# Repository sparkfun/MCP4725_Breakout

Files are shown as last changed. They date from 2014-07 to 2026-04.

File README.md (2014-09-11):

MCP4725_Breakout
================
[MCP4725_Breakout  
*Breakout Board for MCP4725 I2C DAC (BOB-12918)*](https://www.sparkfun.com/products/12918)

The MCP4725 is an I<sup>2</sup>C controlled Digital-to-Analog converter (DAC). It allows you to send an analog signal from a digital source.

Repository Contents
-------------------
* **/Hardware** - Eagle PCB layout files
* **/Production** - Test bed files and production panel files

Version History
---------------
* [BOB-08736](https://www.sparkfun.com/products/8736) -Version 1.3. Now retired. 

License Information
-------------------
The hardware is released under [Creative Commons ShareAlike 4.0 International](https://creativecommons.org/licenses/by-sa/4.0/).
The code is beerware; if you see me (or any other SparkFun employee) at the local, and you've found our code helpful, please buy us a round!

Distributed as-is; no warranty is given.

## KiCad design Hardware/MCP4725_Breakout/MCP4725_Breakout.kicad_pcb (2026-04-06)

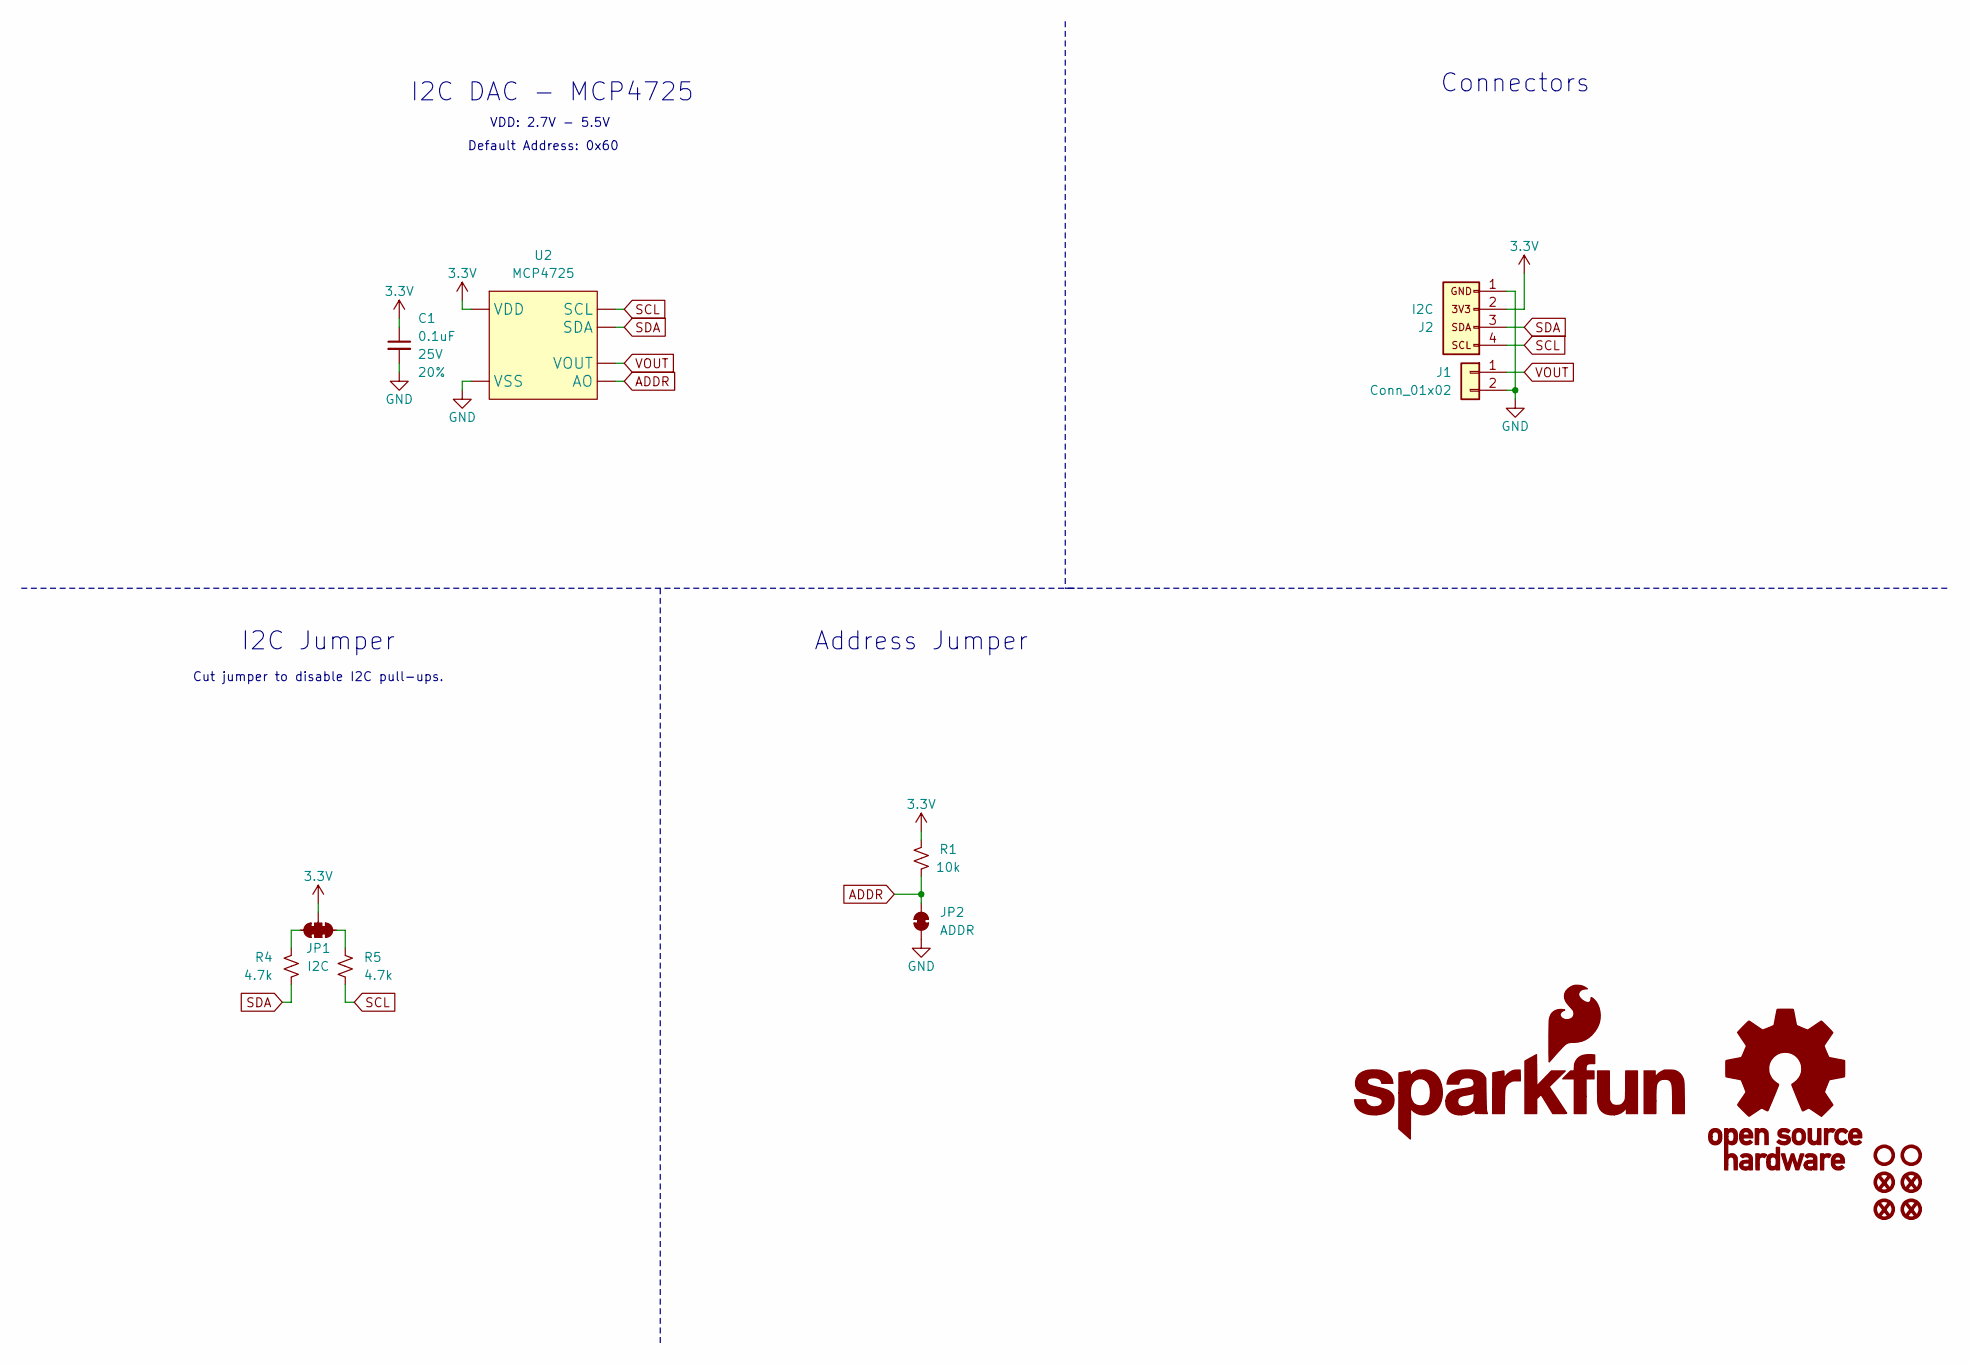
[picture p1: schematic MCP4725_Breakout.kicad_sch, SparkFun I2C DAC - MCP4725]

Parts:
C1: 0.1uF; C_0603_1608Metric; Voltage 25V; Tolerance 20%
FID1, FID2, FID3, FID4: Fiducial_0.5mm; Fiducial_0.5mm_Mask1mm
G1: OSHW_Logo; Creative_Commons_License
G2: SparkFun_Logo
J1: Conn_01x02; 1x02_P2.54mm
J2: I2C; 1x04_P2.54mm
JP1: I2C; Jumper_3_NC-2_Trace
JP2: ADDR; Jumper_2_NC_Trace
R1: 10k; R_0603_1608Metric
R4, R5: 4.7k; R_0603_1608Metric
ST1, ST2: Standoff
U2: MCP4725; SOT23-6

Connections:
3.3V: C1.1, J2.2, JP1.2 (B), R1.2, U2.3 (VDD)
ADDR: JP2.2 (B), R1.1, U2.6 (AO)
GND: C1.2, J1.2, J2.1, JP2.1 (A), U2.2 (VSS)
unnamed: JP1.1 (A), R5.2
unnamed: JP1.3 (C), R4.2
SCL: J2.4, R5.1, U2.5 (SCL)
SDA: J2.3, R4.1, U2.4 (SDA)
VOUT: J1.1, U2.1 (VOUT)

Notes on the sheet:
Default Address: 0x60
VDD: 2.7V - 5.5V
I2C DAC - MCP4725
Cut jumper to disable I2C pull-ups.
Address Jumper
I2C Jumper
Connectors

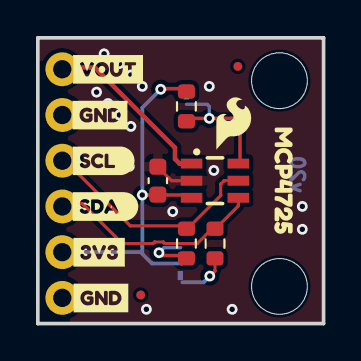
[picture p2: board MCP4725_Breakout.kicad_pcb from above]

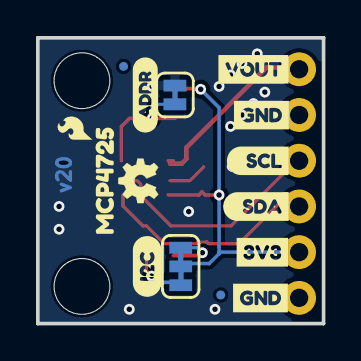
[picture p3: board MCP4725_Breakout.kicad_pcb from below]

Board: 2 copper layers, 15.9 x 15.9 mm, 33 parts (14 on the bottom side), 8 nets.

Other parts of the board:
Ref**: Val**; OSHW_Logo_2.5mm
kibuzzard-69B46D81, kibuzzard-69B46D81#2: G***; kibuzzard-69B46D81
kibuzzard-69B46D94, kibuzzard-69B46D94#2, kibuzzard-69B46D94#3, kibuzzard-69B46D94#4: G***; kibuzzard-69B46D94
kibuzzard-69B46DE0, kibuzzard-69B46DE0#2: G***; kibuzzard-69B46DE0
kibuzzard-69B46E1A, kibuzzard-69B46E1A#2: G***; kibuzzard-69B46E1A
kibuzzard-69B46E2A: G***; kibuzzard-69B46E2A
kibuzzard-69B46E2F: G***; kibuzzard-69B46E2F
kibuzzard-69B46E88: G***; kibuzzard-69B46E88
kibuzzard-69B46EE5: G***; kibuzzard-69B46EE5
kibuzzard-69B46EEC: G***; kibuzzard-69B46EEC
kibuzzard-69B976CB: G***; kibuzzard-69B976CB

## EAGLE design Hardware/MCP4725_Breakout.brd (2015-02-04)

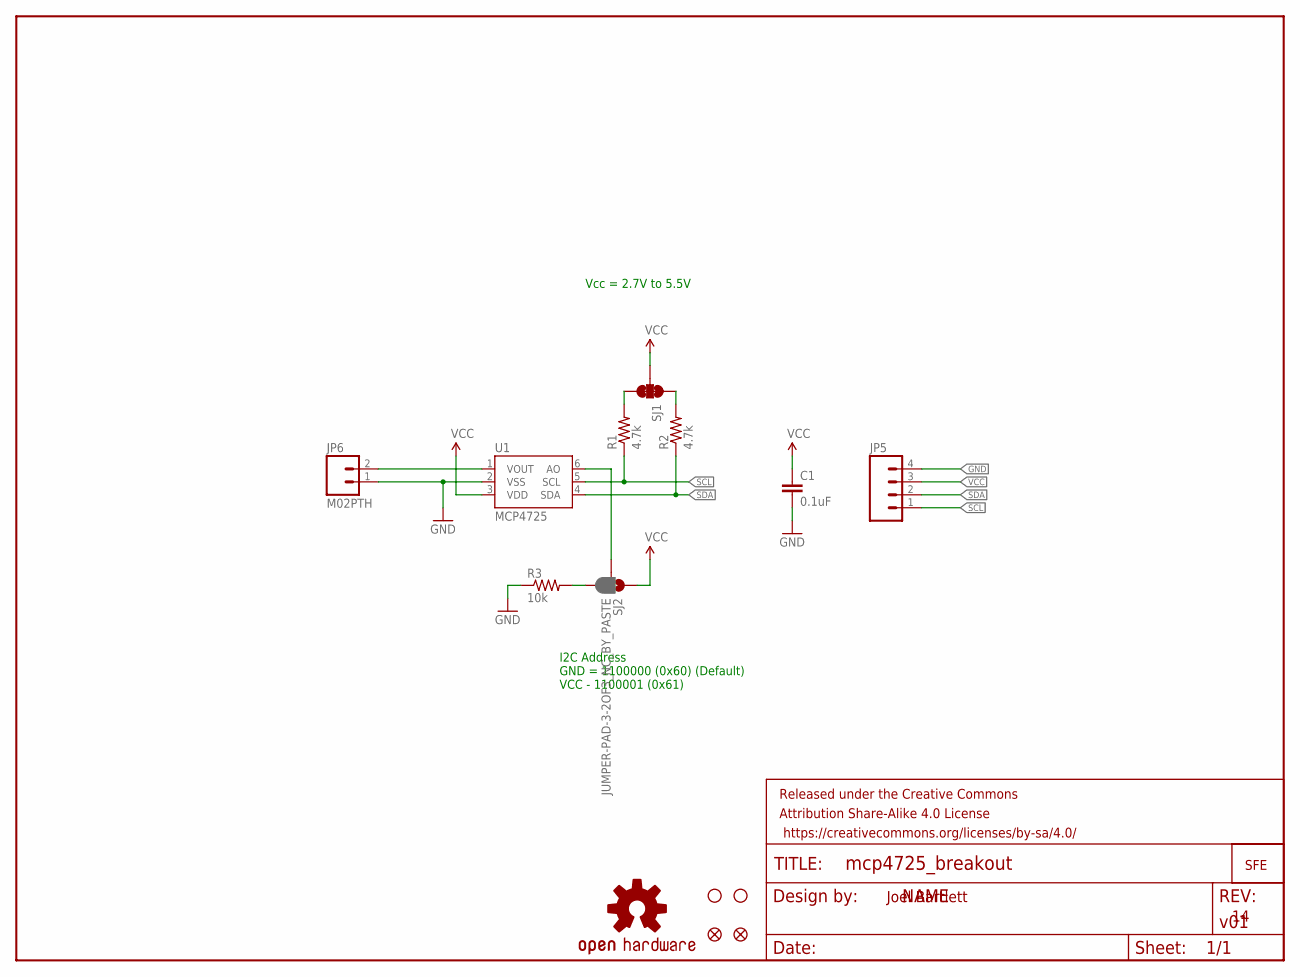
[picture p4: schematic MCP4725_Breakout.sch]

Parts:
C1: 0.1uF; 0603-CAP
FID1, FID2: FIDUCIAL1X2; FIDUCIAL-1X2
FRAME2: FRAME-LETTER; CREATIVE_COMMONS
GND: LOGO-SFESK; SFE-LOGO-FLAME
JP5: M04PTH; 1X04
JP6: M02PTH; 1X02
LOGO1: OSHW-LOGOS; OSHW-LOGO-S
R1, R2: 4.7k; 0603-RES
R3: 10k; 0603-RES
SJ1: JUMPER-PAD-3-NC_BY_TRACE; PAD-JUMPER-3-3OF3_NC_BY_TRACE_YES_SILK_FULL_BOX
SJ2: JUMPER-PAD-3-2OF3_NC_BY_PASTE; PAD-JUMPER-3-2OF3_NC_BY_PASTE_YES_SILK_FULL_BOX
STANDOFF1, STANDOFF2: STAND-OFF
U1: MCP4725; SOT23-6

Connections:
GND: C1.2, JP5.4, JP6.1, R3.1, U1.2 (VSS)
unnamed: R2.2, SJ1.1
unnamed: R1.2, SJ1.3
unnamed: SJ2.2, U1.6 (AO)
unnamed: R3.2, SJ2.3
SCL: JP5.1, R1.1, U1.5 (SCL)
SDA: JP5.2, R2.1, U1.4 (SDA)
VCC: C1.1, JP5.3, SJ1.2, SJ2.1, U1.3 (VDD)
VOUT: JP6.2, U1.1 (VOUT)

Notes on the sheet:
I2C Address GND = 1100000 (0x60) (Default) VCC - 1100001 (0x61)
Joel Bartlett
Vcc = 2.7V to 5.5V

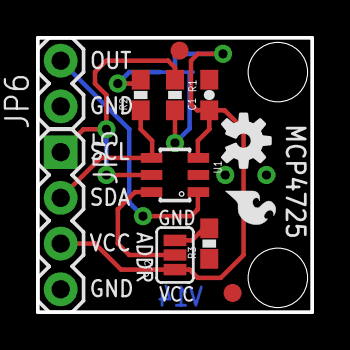
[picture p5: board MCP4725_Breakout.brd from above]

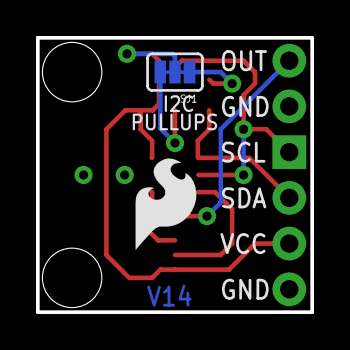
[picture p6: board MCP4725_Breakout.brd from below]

Board: 2 copper layers, 15.2 x 15.2 mm, 17 parts (2 on the bottom side), 9 nets.

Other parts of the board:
U$3: SFE_LOGO_FLAME_.2

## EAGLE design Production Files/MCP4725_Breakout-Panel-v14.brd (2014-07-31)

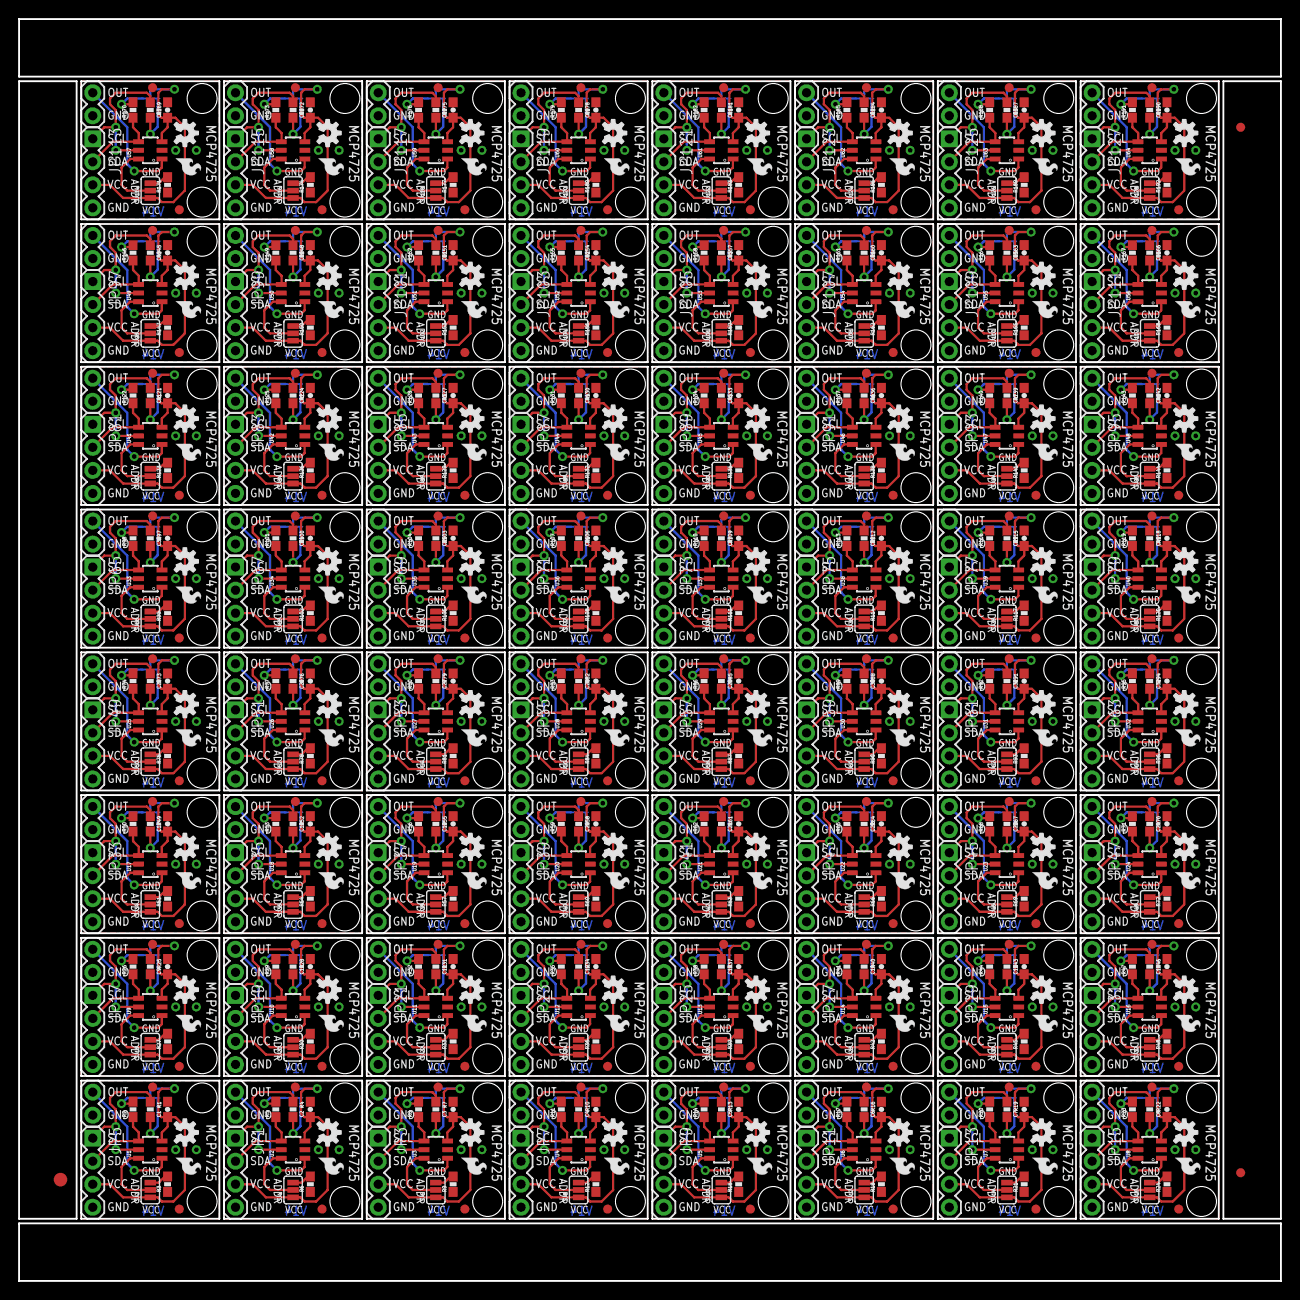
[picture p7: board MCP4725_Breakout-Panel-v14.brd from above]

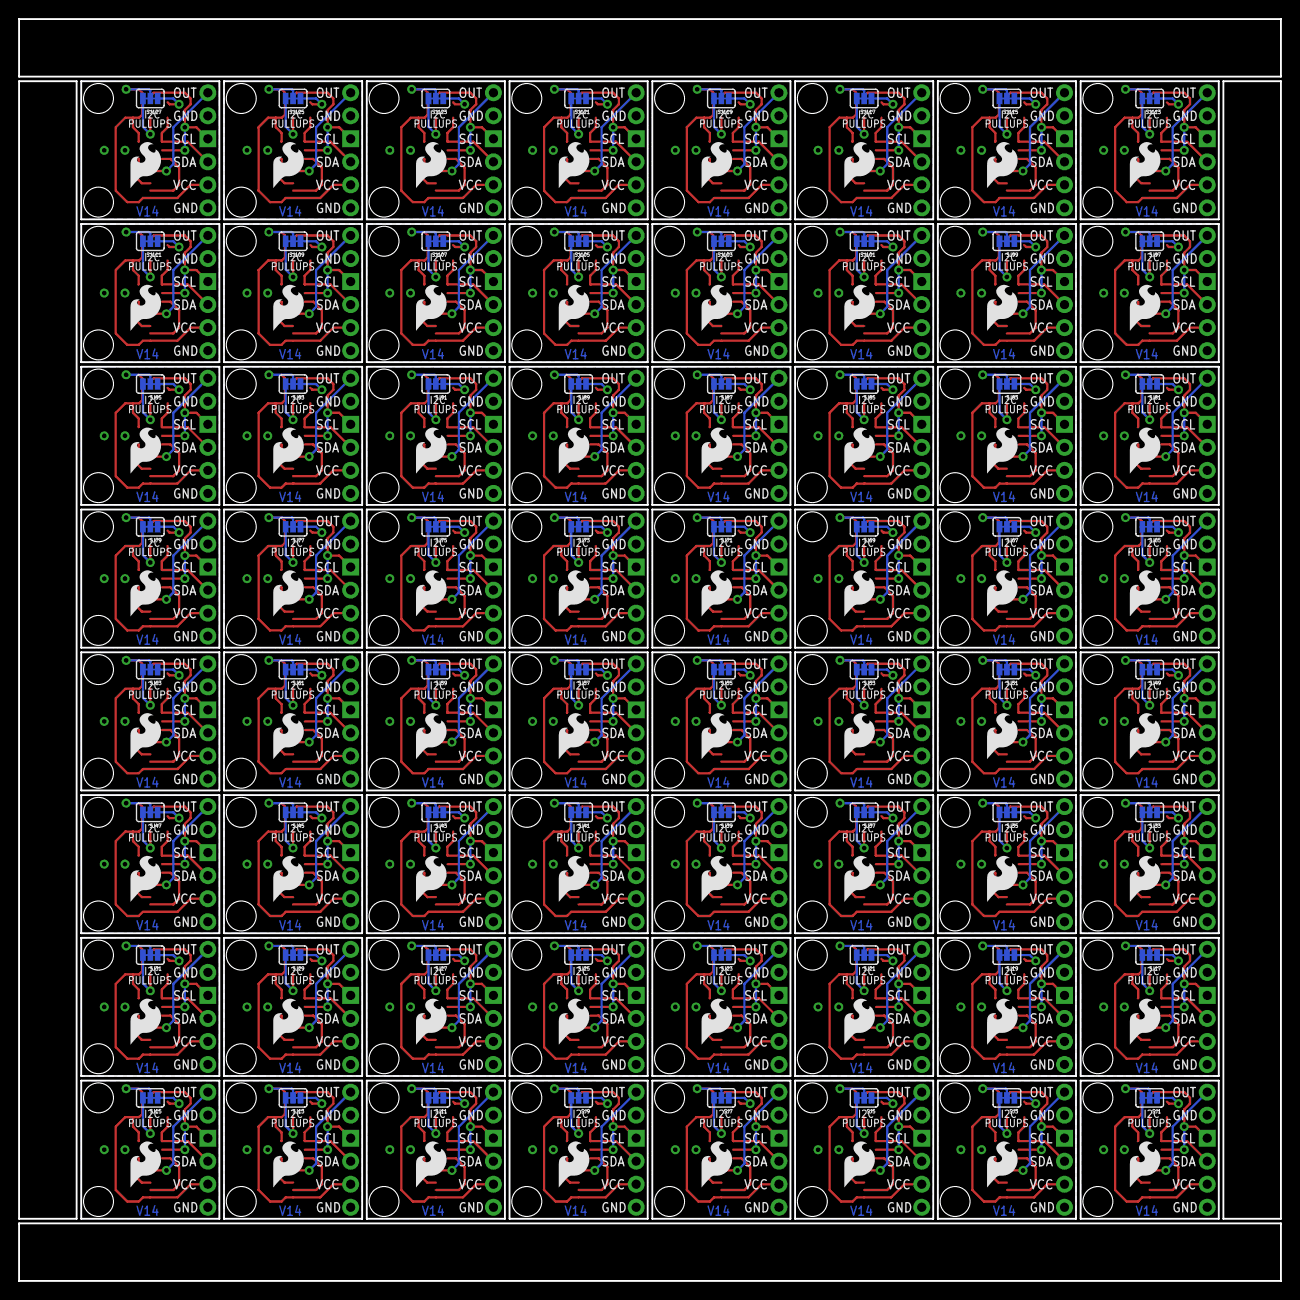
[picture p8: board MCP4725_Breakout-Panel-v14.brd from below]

Board: 2 copper layers, 139.2 x 139.2 mm, 1027 parts (128 on the bottom side), 576 nets.

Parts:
C1, C2, C3, C4, C5, C6, C7, C8, C9, C10, C11, C12, C13, C14, C15, C16, C17, C18, C19, C20, C21, C22, C23, C24, C25, C26, C27, C28, C29, C30, C31, C32, C33, C34, C35, C36, C37, C38, C39, C40, C41, C42, C43, C44, C45, C46, C47, C48, C49, C50, C51, C52, C53, C54, C55, C56, C57, C58, C59, C60, C61, C62, C63, C64: 0.1uF; 0603-CAP
E$1: FIDUCIAL-1.5X3
E$4, E$5: FIDUCIAL-1X2
FID1, FID2, FID3, FID4, FID5, FID6, FID7, FID8, FID9, FID10, FID11, FID12, FID13, FID14, FID15, FID16, FID17, FID18, FID19, FID20, FID21, FID22, FID23, FID24, FID25, FID26, FID27, FID28, FID29, FID30, FID31, FID32, FID33, FID34, FID35, FID36, FID37, FID38, FID39, FID40, FID41, FID42, FID43, FID44, FID45, FID46, FID47, FID48, FID49, FID50, FID51, FID52, FID53, FID54, FID55, FID56, FID57, FID58, FID59, FID60, FID61, FID62, FID63, FID64, FID65, FID66, FID67, FID68, FID69, FID70, FID71, FID72, FID73, FID74, FID75, FID76, FID77, FID78, FID79, FID80, FID81, FID82, FID83, FID84, FID85, FID86, FID87, FID88, FID89, FID90, FID91, FID92, FID93, FID94, FID95, FID96, FID97, FID98, FID99, FID100, FID101, FID102, FID103, FID104, FID105, FID106, FID107, FID108, FID109, FID110, FID111, FID112, FID113, FID114, FID115, FID116, FID117, FID118, FID119, FID120, FID121, FID122, FID123, FID124, FID125, FID126, FID127, FID128: FIDUCIAL1X2; FIDUCIAL-1X2
GND, GND1, GND2, GND3, GND4, GND5, GND6, GND7, GND8, GND9, GND10, GND11, GND12, GND13, GND14, GND15, GND16, GND17, GND18, GND19, GND20, GND21, GND22, GND23, GND24, GND25, GND26, GND27, GND28, GND29, GND30, GND31, GND32, GND33, GND34, GND35, GND36, GND37, GND38, GND39, GND40, GND41, GND42, GND43, GND44, GND45, GND46, GND47, GND48, GND49, GND50, GND51, GND52, GND53, GND54, GND55, GND56, GND57, GND58, GND59, GND60, GND61, GND62, GND63: LOGO-SFESK; SFE-LOGO-FLAME
JP1, JP3, JP5, JP7, JP9, JP11, JP13, JP15, JP17, JP19, JP21, JP23, JP25, JP27, JP29, JP31, JP33, JP35, JP37, JP39, JP41, JP43, JP45, JP47, JP49, JP51, JP53, JP55, JP57, JP59, JP61, JP63, JP65, JP67, JP69, JP71, JP73, JP75, JP77, JP79, JP81, JP83, JP85, JP87, JP89, JP91, JP93, JP95, JP97, JP99, JP101, JP103, JP105, JP107, JP109, JP111, JP113, JP115, JP117, JP119, JP121, JP123, JP125, JP127: 1X04
JP2, JP4, JP6, JP8, JP10, JP12, JP14, JP16, JP18, JP20, JP22, JP24, JP26, JP28, JP30, JP32, JP34, JP36, JP38, JP40, JP42, JP44, JP46, JP48, JP50, JP52, JP54, JP56, JP58, JP60, JP62, JP64, JP66, JP68, JP70, JP72, JP74, JP76, JP78, JP80, JP82, JP84, JP86, JP88, JP90, JP92, JP94, JP96, JP98, JP100, JP102, JP104, JP106, JP108, JP110, JP112, JP114, JP116, JP118, JP120, JP122, JP124, JP126, JP128: M02PTH; 1X02
LOGO1, LOGO2, LOGO3, LOGO4, LOGO5, LOGO6, LOGO7, LOGO8, LOGO9, LOGO10, LOGO11, LOGO12, LOGO13, LOGO14, LOGO15, LOGO16, LOGO17, LOGO18, LOGO19, LOGO20, LOGO21, LOGO22, LOGO23, LOGO24, LOGO25, LOGO26, LOGO27, LOGO28, LOGO29, LOGO30, LOGO31, LOGO32, LOGO33, LOGO34, LOGO35, LOGO36, LOGO37, LOGO38, LOGO39, LOGO40, LOGO41, LOGO42, LOGO43, LOGO44, LOGO45, LOGO46, LOGO47, LOGO48, LOGO49, LOGO50, LOGO51, LOGO52, LOGO53, LOGO54, LOGO55, LOGO56, LOGO57, LOGO58, LOGO59, LOGO60, LOGO61, LOGO62, LOGO63, LOGO64: OSHW-LOGOS; OSHW-LOGO-S
R1, R2, R4, R5, R7, R8, R10, R11, R13, R14, R16, R17, R19, R20, R22, R23, R25, R26, R28, R29, R31, R32, R34, R35, R37, R38, R40, R41, R43, R44, R46, R47, R49, R50, R52, R53, R55, R56, R58, R59, R61, R62, R64, R65, R67, R68, R70, R71, R73, R74, R76, R77, R79, R80, R82, R83, R85, R86, R88, R89, R91, R92, R94, R95, R97, R98, R100, R101, R103, R104, R106, R107, R109, R110, R112, R113, R115, R116, R118, R119, R121, R122, R124, R125, R127, R128, R130, R131, R133, R134, R136, R137, R139, R140, R142, R143, R145, R146, R148, R149, R151, R152, R154, R155, R157, R158, R160, R161, R163, R164, R166, R167, R169, R170, R172, R173, R175, R176, R178, R179, R181, R182, R184, R185, R187, R188, R190, R191: 4.7k; 0603-RES
R3, R6, R9, R12, R15, R18, R21, R24, R27, R30, R33, R36, R39, R42, R45, R48, R51, R54, R57, R60, R63, R66, R69, R72, R75, R78, R81, R84, R87, R90, R93, R96, R99, R102, R105, R108, R111, R114, R117, R120, R123, R126, R129, R132, R135, R138, R141, R144, R147, R150, R153, R156, R159, R162, R165, R168, R171, R174, R177, R180, R183, R186, R189, R192: 10k; 0603-RES
SJ1, SJ3, SJ5, SJ7, SJ9, SJ11, SJ13, SJ15, SJ17, SJ19, SJ21, SJ23, SJ25, SJ27, SJ29, SJ31, SJ33, SJ35, SJ37, SJ39, SJ41, SJ43, SJ45, SJ47, SJ49, SJ51, SJ53, SJ55, SJ57, SJ59, SJ61, SJ63, SJ65, SJ67, SJ69, SJ71, SJ73, SJ75, SJ77, SJ79, SJ81, SJ83, SJ85, SJ87, SJ89, SJ91, SJ93, SJ95, SJ97, SJ99, SJ101, SJ103, SJ105, SJ107, SJ109, SJ111, SJ113, SJ115, SJ117, SJ119, SJ121, SJ123, SJ125, SJ127: PAD-JUMPER-3-3OF3_NC_BY_TRACE_YES_SILK_FULL_BOX
SJ2, SJ4, SJ6, SJ8, SJ10, SJ12, SJ14, SJ16, SJ18, SJ20, SJ22, SJ24, SJ26, SJ28, SJ30, SJ32, SJ34, SJ36, SJ38, SJ40, SJ42, SJ44, SJ46, SJ48, SJ50, SJ52, SJ54, SJ56, SJ58, SJ60, SJ62, SJ64, SJ66, SJ68, SJ70, SJ72, SJ74, SJ76, SJ78, SJ80, SJ82, SJ84, SJ86, SJ88, SJ90, SJ92, SJ94, SJ96, SJ98, SJ100, SJ102, SJ104, SJ106, SJ108, SJ110, SJ112, SJ114, SJ116, SJ118, SJ120, SJ122, SJ124, SJ126, SJ128: PAD-JUMPER-3-2OF3_NC_BY_PASTE_YES_SILK_FULL_BOX
STANDOFF1, STANDOFF2, STANDOFF3, STANDOFF4, STANDOFF5, STANDOFF6, STANDOFF7, STANDOFF8, STANDOFF9, STANDOFF10, STANDOFF11, STANDOFF12, STANDOFF13, STANDOFF14, STANDOFF15, STANDOFF16, STANDOFF17, STANDOFF18, STANDOFF19, STANDOFF20, STANDOFF21, STANDOFF22, STANDOFF23, STANDOFF24, STANDOFF25, STANDOFF26, STANDOFF27, STANDOFF28, STANDOFF29, STANDOFF30, STANDOFF31, STANDOFF32, STANDOFF33, STANDOFF34, STANDOFF35, STANDOFF36, STANDOFF37, STANDOFF38, STANDOFF39, STANDOFF40, STANDOFF41, STANDOFF42, STANDOFF43, STANDOFF44, STANDOFF45, STANDOFF46, STANDOFF47, STANDOFF48, STANDOFF49, STANDOFF50, STANDOFF51, STANDOFF52, STANDOFF53, STANDOFF54, STANDOFF55, STANDOFF56, STANDOFF57, STANDOFF58, STANDOFF59, STANDOFF60, STANDOFF61, STANDOFF62, STANDOFF63, STANDOFF64, STANDOFF65, STANDOFF66, STANDOFF67, STANDOFF68, STANDOFF69, STANDOFF70, STANDOFF71, STANDOFF72, STANDOFF73, STANDOFF74, STANDOFF75, STANDOFF76, STANDOFF77, STANDOFF78, STANDOFF79, STANDOFF80, STANDOFF81, STANDOFF82, STANDOFF83, STANDOFF84, STANDOFF85, STANDOFF86, STANDOFF87, STANDOFF88, STANDOFF89, STANDOFF90, STANDOFF91, STANDOFF92, STANDOFF93, STANDOFF94, STANDOFF95, STANDOFF96, STANDOFF97, STANDOFF98, STANDOFF99, STANDOFF100, STANDOFF101, STANDOFF102, STANDOFF103, STANDOFF104, STANDOFF105, STANDOFF106, STANDOFF107, STANDOFF108, STANDOFF109, STANDOFF110, STANDOFF111, STANDOFF112, STANDOFF113, STANDOFF114, STANDOFF115, STANDOFF116, STANDOFF117, STANDOFF118, STANDOFF119, STANDOFF120, STANDOFF121, STANDOFF122, STANDOFF123, STANDOFF124, STANDOFF125, STANDOFF126, STANDOFF127, STANDOFF128: STAND-OFF
U1, U2, U3, U4, U5, U6, U7, U8, U9, U10, U11, U12, U13, U14, U15, U16, U17, U18, U19, U20, U21, U22, U23, U24, U25, U26, U27, U28, U29, U30, U31, U32, U33, U34, U35, U36, U37, U38, U39, U40, U41, U42, U43, U44, U45, U46, U47, U48, U49, U50, U51, U52, U53, U54, U55, U56, U57, U58, U59, U60, U61, U62, U63, U64: DAC_MCP4725SOT-CP; SOT23-6-MCP4725
U$1, U$2, U$3, U$4, U$5, U$6, U$7, U$8, U$9, U$10, U$11, U$12, U$13, U$14, U$15, U$16, U$17, U$18, U$19, U$20, U$21, U$22, U$23, U$24, U$25, U$26, U$27, U$28, U$29, U$30, U$31, U$32, U$33, U$34, U$35, U$36, U$37, U$38, U$39, U$40, U$41, U$42, U$43, U$44, U$45, U$46, U$47, U$48, U$49, U$50, U$51, U$52, U$53, U$54, U$55, U$56, U$57, U$58, U$59, U$60, U$61, U$62, U$63, U$64: SFE_LOGO_FLAME_.2

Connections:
GND: C1.2, JP5.4, JP6.1, R3.1, U1.2
GND1: C2.2, JP1.4, JP2.1, R6.1, U2.2
GND2: C3.2, JP3.4, JP4.1, R9.1, U3.2
GND3: C4.2, JP7.4, JP8.1, R12.1, U4.2
GND4: C5.2, JP9.4, JP10.1, R15.1, U5.2
GND5: C6.2, JP11.4, JP12.1, R18.1, U6.2
GND6: C7.2, JP13.4, JP14.1, R21.1, U7.2
GND7: C8.2, JP15.4, JP16.1, R24.1, U8.2
GND8: C9.2, JP17.4, JP18.1, R27.1, U9.2
GND9: C10.2, JP19.4, JP20.1, R30.1, U10.2
GND10: C11.2, JP21.4, JP22.1, R33.1, U11.2
GND11: C12.2, JP23.4, JP24.1, R36.1, U12.2
GND12: C13.2, JP25.4, JP26.1, R39.1, U13.2
GND13: C14.2, JP27.4, JP28.1, R42.1, U14.2
GND14: C15.2, JP29.4, JP30.1, R45.1, U15.2
GND15: C16.2, JP31.4, JP32.1, R48.1, U16.2
GND16: C17.2, JP33.4, JP34.1, R51.1, U17.2
GND17: C18.2, JP35.4, JP36.1, R54.1, U18.2
GND18: C19.2, JP37.4, JP38.1, R57.1, U19.2
GND19: C20.2, JP39.4, JP40.1, R60.1, U20.2
GND20: C21.2, JP41.4, JP42.1, R63.1, U21.2
GND21: C22.2, JP43.4, JP44.1, R66.1, U22.2
GND22: C23.2, JP45.4, JP46.1, R69.1, U23.2
GND23: C24.2, JP47.4, JP48.1, R72.1, U24.2
GND24: C25.2, JP49.4, JP50.1, R75.1, U25.2
GND25: C26.2, JP51.4, JP52.1, R78.1, U26.2
GND26: C27.2, JP53.4, JP54.1, R81.1, U27.2
GND27: C28.2, JP55.4, JP56.1, R84.1, U28.2
GND28: C29.2, JP57.4, JP58.1, R87.1, U29.2
GND29: C30.2, JP59.4, JP60.1, R90.1, U30.2
GND30: C31.2, JP61.4, JP62.1, R93.1, U31.2
GND31: C32.2, JP63.4, JP64.1, R96.1, U32.2
GND32: C33.2, JP65.4, JP66.1, R99.1, U33.2
GND33: C34.2, JP67.4, JP68.1, R102.1, U34.2
GND34: C35.2, JP69.4, JP70.1, R105.1, U35.2
GND35: C36.2, JP71.4, JP72.1, R108.1, U36.2
GND36: C37.2, JP73.4, JP74.1, R111.1, U37.2
GND37: C38.2, JP75.4, JP76.1, R114.1, U38.2
GND38: C39.2, JP77.4, JP78.1, R117.1, U39.2
GND39: C40.2, JP79.4, JP80.1, R120.1, U40.2
GND40: C41.2, JP81.4, JP82.1, R123.1, U41.2
GND41: C42.2, JP83.4, JP84.1, R126.1, U42.2
GND42: C43.2, JP85.4, JP86.1, R129.1, U43.2
GND43: C44.2, JP87.4, JP88.1, R132.1, U44.2
GND44: C45.2, JP89.4, JP90.1, R135.1, U45.2
GND45: C46.2, JP91.4, JP92.1, R138.1, U46.2
GND46: C47.2, JP93.4, JP94.1, R141.1, U47.2
GND47: C48.2, JP95.4, JP96.1, R144.1, U48.2
GND48: C49.2, JP97.4, JP98.1, R147.1, U49.2
GND49: C50.2, JP99.4, JP100.1, R150.1, U50.2
GND50: C51.2, JP101.4, JP102.1, R153.1, U51.2
GND51: C52.2, JP103.4, JP104.1, R156.1, U52.2
GND52: C53.2, JP105.4, JP106.1, R159.1, U53.2
GND53: C54.2, JP107.4, JP108.1, R162.1, U54.2
GND54: C55.2, JP109.4, JP110.1, R165.1, U55.2
GND55: C56.2, JP111.4, JP112.1, R168.1, U56.2
GND56: C57.2, JP113.4, JP114.1, R171.1, U57.2
GND57: C58.2, JP115.4, JP116.1, R174.1, U58.2
GND58: C59.2, JP117.4, JP118.1, R177.1, U59.2
GND59: C60.2, JP119.4, JP120.1, R180.1, U60.2
GND60: C61.2, JP121.4, JP122.1, R183.1, U61.2
GND61: C62.2, JP123.4, JP124.1, R186.1, U62.2
GND62: C63.2, JP125.4, JP126.1, R189.1, U63.2
GND63: C64.2, JP127.4, JP128.1, R192.1, U64.2
unnamed: R2.2, SJ1.1
unnamed: R1.2, SJ1.3
unnamed: SJ2.2, U1.4
unnamed: R3.2, SJ2.3
unnamed: R5.2, SJ3.1
unnamed: R4.2, SJ3.3
unnamed: SJ4.2, U2.4
unnamed: R6.2, SJ4.3
unnamed: R8.2, SJ5.1
unnamed: R7.2, SJ5.3
unnamed: SJ6.2, U3.4
unnamed: R9.2, SJ6.3
unnamed: R11.2, SJ7.1
unnamed: R10.2, SJ7.3
unnamed: SJ8.2, U4.4
unnamed: R12.2, SJ8.3
unnamed: R14.2, SJ9.1
unnamed: R13.2, SJ9.3
unnamed: SJ10.2, U5.4
unnamed: R15.2, SJ10.3
unnamed: R17.2, SJ11.1
unnamed: R16.2, SJ11.3
unnamed: SJ12.2, U6.4
unnamed: R18.2, SJ12.3
unnamed: R20.2, SJ13.1
unnamed: R19.2, SJ13.3
unnamed: SJ14.2, U7.4
unnamed: R21.2, SJ14.3
unnamed: R23.2, SJ15.1
unnamed: R22.2, SJ15.3
unnamed: SJ16.2, U8.4
unnamed: R24.2, SJ16.3
unnamed: R26.2, SJ17.1
unnamed: R25.2, SJ17.3
unnamed: SJ18.2, U9.4
unnamed: R27.2, SJ18.3
unnamed: R29.2, SJ19.1
unnamed: R28.2, SJ19.3
unnamed: SJ20.2, U10.4
unnamed: R30.2, SJ20.3
unnamed: R32.2, SJ21.1
unnamed: R31.2, SJ21.3
unnamed: SJ22.2, U11.4
unnamed: R33.2, SJ22.3
unnamed: R35.2, SJ23.1
unnamed: R34.2, SJ23.3
unnamed: SJ24.2, U12.4
unnamed: R36.2, SJ24.3
unnamed: R38.2, SJ25.1
unnamed: R37.2, SJ25.3
unnamed: SJ26.2, U13.4
unnamed: R39.2, SJ26.3
unnamed: R41.2, SJ27.1
unnamed: R40.2, SJ27.3
unnamed: SJ28.2, U14.4
unnamed: R42.2, SJ28.3
unnamed: R44.2, SJ29.1
unnamed: R43.2, SJ29.3
unnamed: SJ30.2, U15.4
unnamed: R45.2, SJ30.3
unnamed: R47.2, SJ31.1
unnamed: R46.2, SJ31.3
unnamed: SJ32.2, U16.4
unnamed: R48.2, SJ32.3
unnamed: R50.2, SJ33.1
unnamed: R49.2, SJ33.3
unnamed: SJ34.2, U17.4
unnamed: R51.2, SJ34.3
unnamed: R53.2, SJ35.1
unnamed: R52.2, SJ35.3
unnamed: SJ36.2, U18.4
unnamed: R54.2, SJ36.3
unnamed: R56.2, SJ37.1
unnamed: R55.2, SJ37.3
unnamed: SJ38.2, U19.4
unnamed: R57.2, SJ38.3
unnamed: R59.2, SJ39.1
unnamed: R58.2, SJ39.3
unnamed: SJ40.2, U20.4
unnamed: R60.2, SJ40.3
unnamed: R62.2, SJ41.1
unnamed: R61.2, SJ41.3
unnamed: SJ42.2, U21.4
unnamed: R63.2, SJ42.3
unnamed: R65.2, SJ43.1
unnamed: R64.2, SJ43.3
unnamed: SJ44.2, U22.4
unnamed: R66.2, SJ44.3
unnamed: R68.2, SJ45.1
unnamed: R67.2, SJ45.3
unnamed: SJ46.2, U23.4
unnamed: R69.2, SJ46.3
unnamed: R71.2, SJ47.1
unnamed: R70.2, SJ47.3
unnamed: SJ48.2, U24.4
unnamed: R72.2, SJ48.3
unnamed: R74.2, SJ49.1
unnamed: R73.2, SJ49.3
unnamed: SJ50.2, U25.4
unnamed: R75.2, SJ50.3
unnamed: R77.2, SJ51.1
unnamed: R76.2, SJ51.3
unnamed: SJ52.2, U26.4
unnamed: R78.2, SJ52.3
unnamed: R80.2, SJ53.1
unnamed: R79.2, SJ53.3
unnamed: SJ54.2, U27.4
unnamed: R81.2, SJ54.3
unnamed: R83.2, SJ55.1
unnamed: R82.2, SJ55.3
unnamed: SJ56.2, U28.4
unnamed: R84.2, SJ56.3
unnamed: R86.2, SJ57.1
unnamed: R85.2, SJ57.3
unnamed: SJ58.2, U29.4
unnamed: R87.2, SJ58.3
unnamed: R89.2, SJ59.1
unnamed: R88.2, SJ59.3
unnamed: SJ60.2, U30.4
unnamed: R90.2, SJ60.3
unnamed: R92.2, SJ61.1
unnamed: R91.2, SJ61.3
unnamed: SJ62.2, U31.4
unnamed: R93.2, SJ62.3
unnamed: R95.2, SJ63.1
unnamed: R94.2, SJ63.3
unnamed: SJ64.2, U32.4
unnamed: R96.2, SJ64.3
unnamed: R98.2, SJ65.1
unnamed: R97.2, SJ65.3
unnamed: SJ66.2, U33.4
unnamed: R99.2, SJ66.3
unnamed: R101.2, SJ67.1
unnamed: R100.2, SJ67.3
unnamed: SJ68.2, U34.4
unnamed: R102.2, SJ68.3
unnamed: R104.2, SJ69.1
unnamed: R103.2, SJ69.3
unnamed: SJ70.2, U35.4
unnamed: R105.2, SJ70.3
unnamed: R107.2, SJ71.1
unnamed: R106.2, SJ71.3
unnamed: SJ72.2, U36.4
unnamed: R108.2, SJ72.3
unnamed: R110.2, SJ73.1
unnamed: R109.2, SJ73.3
unnamed: SJ74.2, U37.4
unnamed: R111.2, SJ74.3
unnamed: R113.2, SJ75.1
unnamed: R112.2, SJ75.3
unnamed: SJ76.2, U38.4
unnamed: R114.2, SJ76.3
unnamed: R116.2, SJ77.1
unnamed: R115.2, SJ77.3
unnamed: SJ78.2, U39.4
unnamed: R117.2, SJ78.3
unnamed: R119.2, SJ79.1
unnamed: R118.2, SJ79.3
unnamed: SJ80.2, U40.4
unnamed: R120.2, SJ80.3
unnamed: R122.2, SJ81.1
unnamed: R121.2, SJ81.3
unnamed: SJ82.2, U41.4
unnamed: R123.2, SJ82.3
unnamed: R125.2, SJ83.1
unnamed: R124.2, SJ83.3
unnamed: SJ84.2, U42.4
unnamed: R126.2, SJ84.3
unnamed: R128.2, SJ85.1
unnamed: R127.2, SJ85.3
unnamed: SJ86.2, U43.4
unnamed: R129.2, SJ86.3
unnamed: R131.2, SJ87.1
unnamed: R130.2, SJ87.3
unnamed: SJ88.2, U44.4
unnamed: R132.2, SJ88.3
unnamed: R134.2, SJ89.1
unnamed: R133.2, SJ89.3
unnamed: SJ90.2, U45.4
unnamed: R135.2, SJ90.3
unnamed: R137.2, SJ91.1
unnamed: R136.2, SJ91.3
unnamed: SJ92.2, U46.4
unnamed: R138.2, SJ92.3
unnamed: R140.2, SJ93.1
unnamed: R139.2, SJ93.3
unnamed: SJ94.2, U47.4
unnamed: R141.2, SJ94.3
unnamed: R143.2, SJ95.1
unnamed: R142.2, SJ95.3
unnamed: SJ96.2, U48.4
unnamed: R144.2, SJ96.3
unnamed: R146.2, SJ97.1
unnamed: R145.2, SJ97.3
unnamed: SJ98.2, U49.4
unnamed: R147.2, SJ98.3
unnamed: R149.2, SJ99.1
unnamed: R148.2, SJ99.3
unnamed: SJ100.2, U50.4
unnamed: R150.2, SJ100.3
unnamed: R152.2, SJ101.1
unnamed: R151.2, SJ101.3
unnamed: SJ102.2, U51.4
unnamed: R153.2, SJ102.3
unnamed: R155.2, SJ103.1
unnamed: R154.2, SJ103.3
unnamed: SJ104.2, U52.4
unnamed: R156.2, SJ104.3
unnamed: R158.2, SJ105.1
unnamed: R157.2, SJ105.3
unnamed: SJ106.2, U53.4
unnamed: R159.2, SJ106.3
unnamed: R161.2, SJ107.1
unnamed: R160.2, SJ107.3
unnamed: SJ108.2, U54.4
unnamed: R162.2, SJ108.3
unnamed: R164.2, SJ109.1
unnamed: R163.2, SJ109.3
unnamed: SJ110.2, U55.4
unnamed: R165.2, SJ110.3
unnamed: R167.2, SJ111.1
unnamed: R166.2, SJ111.3
unnamed: SJ112.2, U56.4
unnamed: R168.2, SJ112.3
unnamed: R170.2, SJ113.1
unnamed: R169.2, SJ113.3
unnamed: SJ114.2, U57.4
unnamed: R171.2, SJ114.3
unnamed: R173.2, SJ115.1
unnamed: R172.2, SJ115.3
unnamed: SJ116.2, U58.4
unnamed: R174.2, SJ116.3
unnamed: R176.2, SJ117.1
unnamed: R175.2, SJ117.3
unnamed: SJ118.2, U59.4
unnamed: R177.2, SJ118.3
unnamed: R179.2, SJ119.1
unnamed: R178.2, SJ119.3
unnamed: SJ120.2, U60.4
unnamed: R180.2, SJ120.3
unnamed: R182.2, SJ121.1
unnamed: R181.2, SJ121.3
unnamed: SJ122.2, U61.4
unnamed: R183.2, SJ122.3
unnamed: R185.2, SJ123.1
unnamed: R184.2, SJ123.3
unnamed: SJ124.2, U62.4
unnamed: R186.2, SJ124.3
unnamed: R188.2, SJ125.1
unnamed: R187.2, SJ125.3
unnamed: SJ126.2, U63.4
unnamed: R189.2, SJ126.3
unnamed: R191.2, SJ127.1
unnamed: R190.2, SJ127.3
unnamed: SJ128.2, U64.4
unnamed: R192.2, SJ128.3
SCL: JP5.1, R1.1, U1.5
SCL1: JP1.1, R4.1, U2.5
SCL2: JP3.1, R7.1, U3.5
SCL3: JP7.1, R10.1, U4.5
SCL4: JP9.1, R13.1, U5.5
SCL5: JP11.1, R16.1, U6.5
SCL6: JP13.1, R19.1, U7.5
SCL7: JP15.1, R22.1, U8.5
SCL8: JP17.1, R25.1, U9.5
SCL9: JP19.1, R28.1, U10.5
SCL10: JP21.1, R31.1, U11.5
SCL11: JP23.1, R34.1, U12.5
SCL12: JP25.1, R37.1, U13.5
SCL13: JP27.1, R40.1, U14.5
SCL14: JP29.1, R43.1, U15.5
SCL15: JP31.1, R46.1, U16.5
SCL16: JP33.1, R49.1, U17.5
SCL17: JP35.1, R52.1, U18.5
SCL18: JP37.1, R55.1, U19.5
SCL19: JP39.1, R58.1, U20.5
SCL20: JP41.1, R61.1, U21.5
SCL21: JP43.1, R64.1, U22.5
SCL22: JP45.1, R67.1, U23.5
SCL23: JP47.1, R70.1, U24.5
SCL24: JP49.1, R73.1, U25.5
SCL25: JP51.1, R76.1, U26.5
SCL26: JP53.1, R79.1, U27.5
SCL27: JP55.1, R82.1, U28.5
SCL28: JP57.1, R85.1, U29.5
SCL29: JP59.1, R88.1, U30.5
SCL30: JP61.1, R91.1, U31.5
SCL31: JP63.1, R94.1, U32.5
SCL32: JP65.1, R97.1, U33.5
SCL33: JP67.1, R100.1, U34.5
SCL34: JP69.1, R103.1, U35.5
SCL35: JP71.1, R106.1, U36.5
SCL36: JP73.1, R109.1, U37.5
SCL37: JP75.1, R112.1, U38.5
SCL38: JP77.1, R115.1, U39.5
SCL39: JP79.1, R118.1, U40.5
SCL40: JP81.1, R121.1, U41.5
SCL41: JP83.1, R124.1, U42.5
SCL42: JP85.1, R127.1, U43.5
SCL43: JP87.1, R130.1, U44.5
SCL44: JP89.1, R133.1, U45.5
SCL45: JP91.1, R136.1, U46.5
SCL46: JP93.1, R139.1, U47.5
SCL47: JP95.1, R142.1, U48.5
SCL48: JP97.1, R145.1, U49.5
SCL49: JP99.1, R148.1, U50.5
SCL50: JP101.1, R151.1, U51.5
SCL51: JP103.1, R154.1, U52.5
SCL52: JP105.1, R157.1, U53.5
SCL53: JP107.1, R160.1, U54.5
SCL54: JP109.1, R163.1, U55.5
SCL55: JP111.1, R166.1, U56.5
SCL56: JP113.1, R169.1, U57.5
SCL57: JP115.1, R172.1, U58.5
SCL58: JP117.1, R175.1, U59.5
SCL59: JP119.1, R178.1, U60.5
SCL60: JP121.1, R181.1, U61.5
SCL61: JP123.1, R184.1, U62.5
SCL62: JP125.1, R187.1, U63.5
SCL63: JP127.1, R190.1, U64.5
SDA: JP5.2, R2.1, U1.6
SDA1: JP1.2, R5.1, U2.6
SDA2: JP3.2, R8.1, U3.6
SDA3: JP7.2, R11.1, U4.6
SDA4: JP9.2, R14.1, U5.6
SDA5: JP11.2, R17.1, U6.6
SDA6: JP13.2, R20.1, U7.6
SDA7: JP15.2, R23.1, U8.6
SDA8: JP17.2, R26.1, U9.6
SDA9: JP19.2, R29.1, U10.6
SDA10: JP21.2, R32.1, U11.6
SDA11: JP23.2, R35.1, U12.6
SDA12: JP25.2, R38.1, U13.6
SDA13: JP27.2, R41.1, U14.6
SDA14: JP29.2, R44.1, U15.6
SDA15: JP31.2, R47.1, U16.6
SDA16: JP33.2, R50.1, U17.6
SDA17: JP35.2, R53.1, U18.6
SDA18: JP37.2, R56.1, U19.6
SDA19: JP39.2, R59.1, U20.6
SDA20: JP41.2, R62.1, U21.6
SDA21: JP43.2, R65.1, U22.6
SDA22: JP45.2, R68.1, U23.6
SDA23: JP47.2, R71.1, U24.6
SDA24: JP49.2, R74.1, U25.6
SDA25: JP51.2, R77.1, U26.6
SDA26: JP53.2, R80.1, U27.6
SDA27: JP55.2, R83.1, U28.6
SDA28: JP57.2, R86.1, U29.6
SDA29: JP59.2, R89.1, U30.6
SDA30: JP61.2, R92.1, U31.6
SDA31: JP63.2, R95.1, U32.6
SDA32: JP65.2, R98.1, U33.6
SDA33: JP67.2, R101.1, U34.6
SDA34: JP69.2, R104.1, U35.6
SDA35: JP71.2, R107.1, U36.6
SDA36: JP73.2, R110.1, U37.6
SDA37: JP75.2, R113.1, U38.6
SDA38: JP77.2, R116.1, U39.6
SDA39: JP79.2, R119.1, U40.6
SDA40: JP81.2, R122.1, U41.6
SDA41: JP83.2, R125.1, U42.6
SDA42: JP85.2, R128.1, U43.6
SDA43: JP87.2, R131.1, U44.6
SDA44: JP89.2, R134.1, U45.6
SDA45: JP91.2, R137.1, U46.6
SDA46: JP93.2, R140.1, U47.6
SDA47: JP95.2, R143.1, U48.6
SDA48: JP97.2, R146.1, U49.6
SDA49: JP99.2, R149.1, U50.6
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

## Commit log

2014-05-06 Lots of changes from v13 to v14
    Committing v_14 changes:
    *Corrected the IC footprint, both the original and Kade's update were
    both incorrect. The pin 1 indicator is now in the correct position.
    *New frame, updated logos, added OSHW logo
    *Switched up pinout for "standard" I2C pinout
    *Added jumper for I2C Address selection
    *Added jumper for I2C pull-up resistors
    *Added standoffs
    * Changed board dimensions to accommodate standoffs and completely
    rerouted the board.
    [MCP4725_v14.brd, MCP4725_v14.sch]
2014-05-21 Addressed issues from first review
    added new jumper packages
    moved and rerouted to avoid cutting of silk text
    added extra GND pad for VOUT
    [MCP4725_v14.brd, MCP4725_v14.sch]
2014-05-29 Final commit before protos
    Changed 10k pull-ups to 4.7k
    Added 10k to prevent shorts on I2C address selection
    Added hex values for address
    added name to symbol layer
    clean up and organize folders
    [MCP4725_v14.brd, MCP4725_v14.sch]
2014-05-29 delete extra .brd file
    delete extra .brd file
    [MCP4725_v14.brd]
2014-07-24 Fixed Silk, OUT and GND were swapped
    Fixed Silk, OUT and GND were swapped
    [MCP4725_v14.brd]
2014-07-29 Last Commit before Reds
    Added my name to brd. file
    added Vcc levels to sch.
    changed file name so version # isn't there
    minor silk fixes due to vias.
    [MCP4725_Breakout.brd, MCP4725_Breakout.sch]
2014-07-30 removed micro fiducial, added regulars
    [MCP4725_Breakout.brd, MCP4725_Breakout.sch]
2014-07-30 changed location of fiducial
    [MCP4725_Breakout.brd]
2014-07-31 created panel v14
    [MCP4725_Breakout-Panel-v14.brd]
2015-02-04 Corrected to generic SOT-23 library
    See engineering file audit, package issues for more information.
    [MCP4725_Breakout.brd, MCP4725_Breakout.sch]
2026-03-11 Imports board files to KiCad
    [MCP4725_Breakout.kicad_pcb, MCP4725_Breakout.kicad_sch]
2026-03-13 Saves progress
    [MCP4725_Breakout.kicad_pcb, MCP4725_Breakout.kicad_sch]
2026-03-17 Adjusts the jumpers on the underside
    [MCP4725_Breakout.kicad_pcb]
2026-03-17 Saves progress before shifting board placement around screw terminals
    [MCP4725_Breakout.kicad_pcb]
2026-03-17 Moves the entire board such that the stand offs and plated through holes
    ...are evenly spaced relative to the edge. The standoffs and plated
    through holes did not move relative to each other.
    [MCP4725_Breakout.kicad_pcb]
2026-03-17 Copies design for Qwiic board
    [MCP4725_Breakout_Qwiic.kicad_pcb, MCP4725_Breakout_Qwiic.kicad_sch]
2026-03-17 Routes Qwiic Board, adds
    [MCP4725_Breakout_Qwiic.kicad_pcb, MCP4725_Breakout_Qwiic.kicad_sch]
2026-03-17 Adds measures, adds silk
    [MCP4725_Breakout_Qwiic.kicad_pcb]
2026-03-18 Fixes DAC symbol, aligns Qwiic connector, removes extra pour
    [MCP4725_Breakout.kicad_pcb, MCP4725_Breakout.kicad_sch, MCP4725_Breakout_Qwiic.kicad_pcb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]
2026-03-18 Fixes swapped pins on SCL/SDA
    [MCP4725_Breakout.kicad_pcb, MCP4725_Breakout.kicad_sch, MCP4725_Breakout_Qwiic.kicad_pcb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]
2026-03-18 Adds new gitignore
    [MCP4725_Breakout.kicad_pcb, MCP4725_Breakout_Qwiic.kicad_pcb]
2026-03-19 Adds Qwiic Logo, power LED, adds "DAC" to product silk
    * Fixes the address jumper
    [MCP4725_Breakout.kicad_pcb, MCP4725_Breakout.kicad_sch, MCP4725_Breakout_Qwiic.kicad_pcb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]
2026-03-19 Changes dual to single jumper
    [MCP4725_Breakout.kicad_pcb, MCP4725_Breakout.kicad_sch, MCP4725_Breakout_Qwiic.kicad_pcb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]
2026-03-19 Fixes jumpers on more time
    [MCP4725_Breakout.kicad_pcb, MCP4725_Breakout.kicad_sch, MCP4725_Breakout_Qwiic.kicad_pcb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]
2026-03-26 Puts PTH on one side
    [MCP4725_Breakout_Qwiic.kicad_pcb]
2026-03-26 Adds measures, grows small board by another 1/8 inch in X/Y direction
    [MCP4725_Breakout.kicad_pcb, MCP4725_Breakout_Qwiic.kicad_pcb, MCP4725_Breakout_Qwiic.kicad_sch]
2026-03-30 Adds gerbers
    [MCP4725_Breakout.kicad_pcb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]
2026-04-02 Fixes trace widths
    [MCP4725_Breakout.kicad_pcb]
2026-04-06 Adds BOM and gerbers for small form factor version
    [MCP4725_Breakout.kicad_pcb, MCP4725_Breakout.kicad_sch]
2026-05-26 Removes 1x1 board
    [MCP4725_Breakout_Qwiic.GBL, MCP4725_Breakout_Qwiic.GBO, MCP4725_Breakout_Qwiic.GBP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]

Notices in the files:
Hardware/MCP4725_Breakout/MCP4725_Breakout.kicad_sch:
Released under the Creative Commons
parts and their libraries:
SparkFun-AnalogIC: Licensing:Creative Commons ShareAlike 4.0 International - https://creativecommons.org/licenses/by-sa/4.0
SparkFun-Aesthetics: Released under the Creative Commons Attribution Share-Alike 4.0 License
